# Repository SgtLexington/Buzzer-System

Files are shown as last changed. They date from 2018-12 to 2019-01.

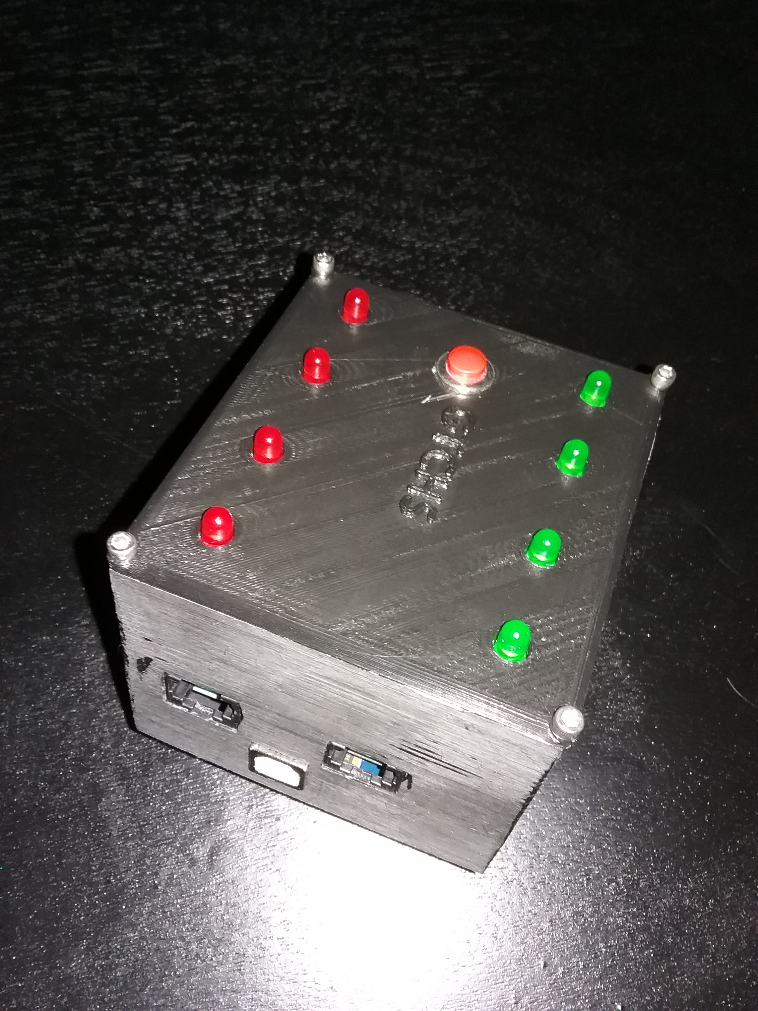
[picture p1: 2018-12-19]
Pictures/20181203_172621.jpg

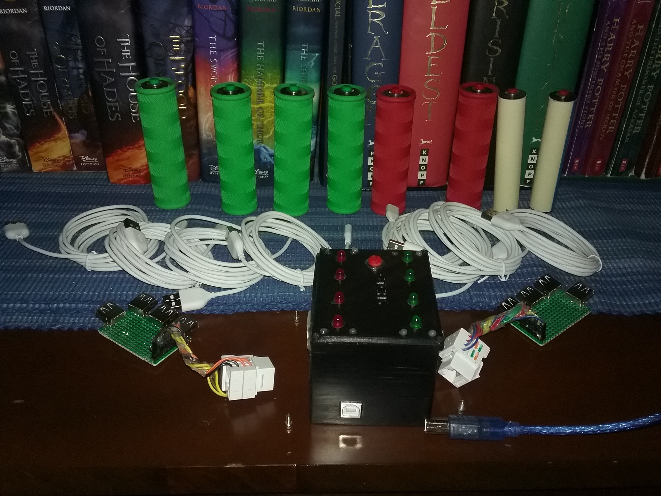
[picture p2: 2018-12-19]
Pictures/20180729_170001.jpg

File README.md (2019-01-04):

# Buzzer-System
The way that academic competitions work is this: to get points, a player must "buzz in" while or after a question has been answered. Then, the player must answer the question correctly. The moderator will take whoever buzzes in first, so it is very important to practice the buzzing motion to do well. My team has lots of talent, but we are always at a disadvantage when we go to competitions becausewe never practice with the equipment that we use at those competions. Usually at practices, to buzz in, we just hit the desk, while at competions there is a handheld buzzer system where the button to buzz in must be activated by a thumb motion. Naturally, we are slightly outperformed in this category by teams that do practice with a real buzzer system. 
The solution is simple: just buy a buzzer system like the ones at the competitions. 
However, decent quality buzzer systems are expensive. Some of the highest quality systems are $200-$300, and my school simply cannot afford something like that. Given that, I decided to make a buzzer system for us.
Not only does having a buzzer system help the team practice better, but if we bring our own buzzer system to a competition, we get a discount on the entry fee.
Here is the finished system:
[insert pic here]
Prototyping
  Protoboards
  Solidworks
The Main Box:
  Arduino Program
  KiCad and PCB
  Solidworks box & lid
The Team Boxes:
  KiCad and PCB
  Solidworks box & lid
The Buzzers:
  Solidworks MicroUSB & button housings

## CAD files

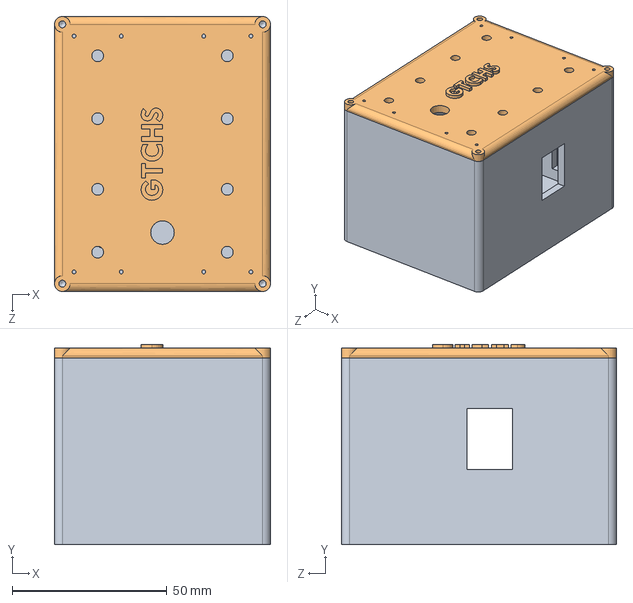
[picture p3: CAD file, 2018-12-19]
SolidWorks/Main box assemb.SLDASM
69.8 x 64.8 x 88.9 mm
Main box
Box lid

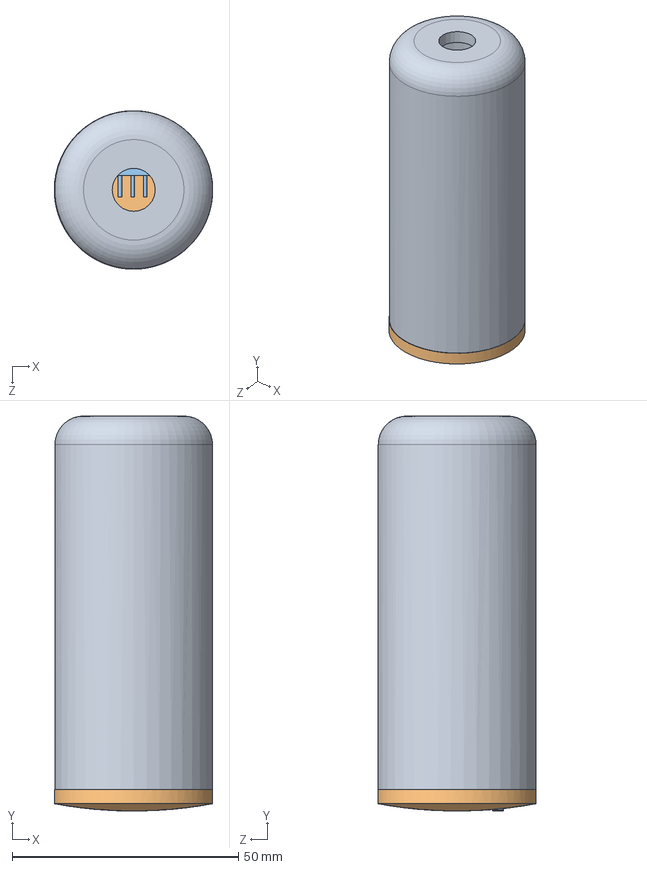
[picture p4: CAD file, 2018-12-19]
SolidWorks/Handheld buzzer housing and breakout board.SLDASM
35.0 x 87.3 x 35.0 mm
Button Housing
Housing bottom
Micro USB Breakout Board

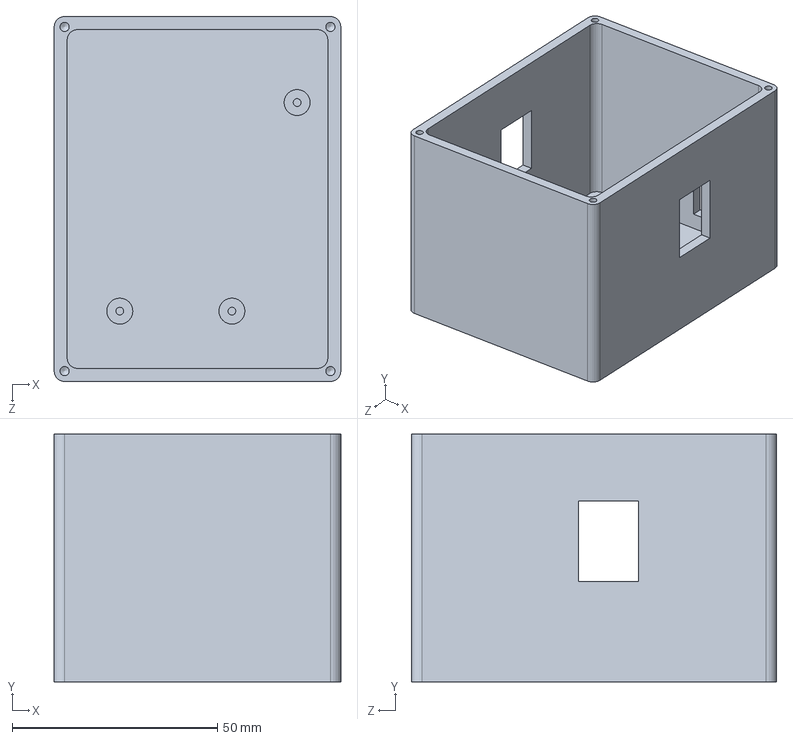
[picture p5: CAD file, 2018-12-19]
SolidWorks/Main box.SLDPRT
69.8 x 60.3 x 88.9 mm

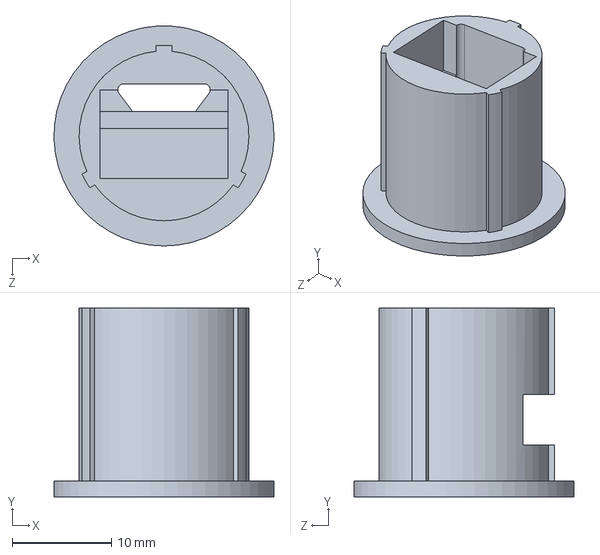
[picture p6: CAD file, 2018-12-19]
SolidWorks/End Cap.SLDPRT
22.2 x 19.1 x 22.2 mm

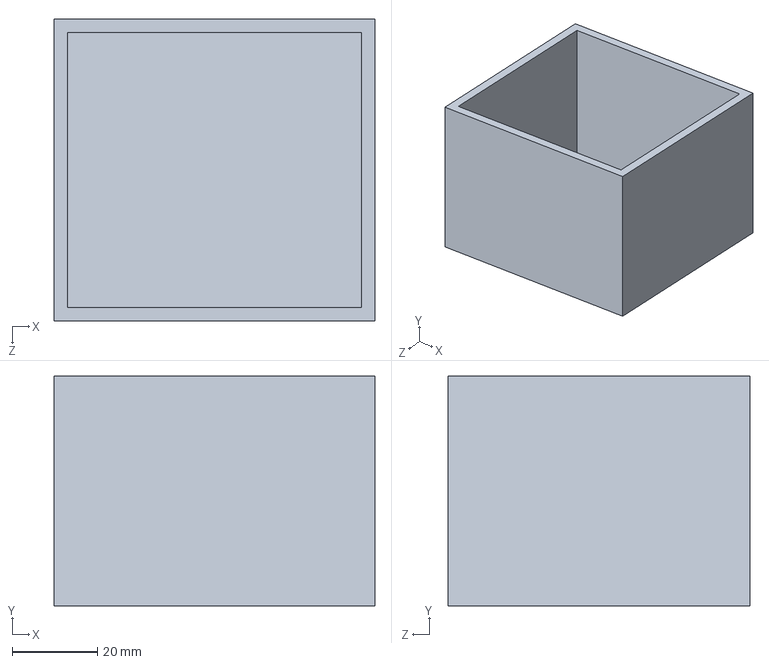
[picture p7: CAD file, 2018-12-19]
SolidWorks/Team box for pcb.SLDPRT
75.4 x 54.0 x 70.9 mm

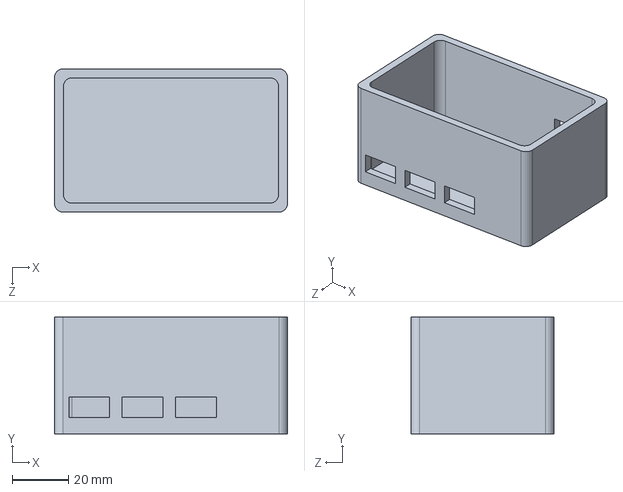
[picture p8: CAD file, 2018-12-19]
SolidWorks/Team box.SLDPRT
82.5 x 41.3 x 50.8 mm

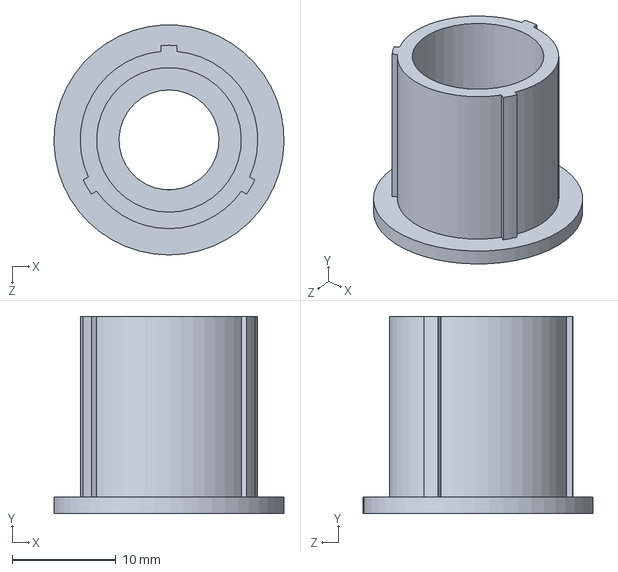
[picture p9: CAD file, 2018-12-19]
SolidWorks/button side end cap.SLDPRT
22.2 x 19.1 x 22.2 mm

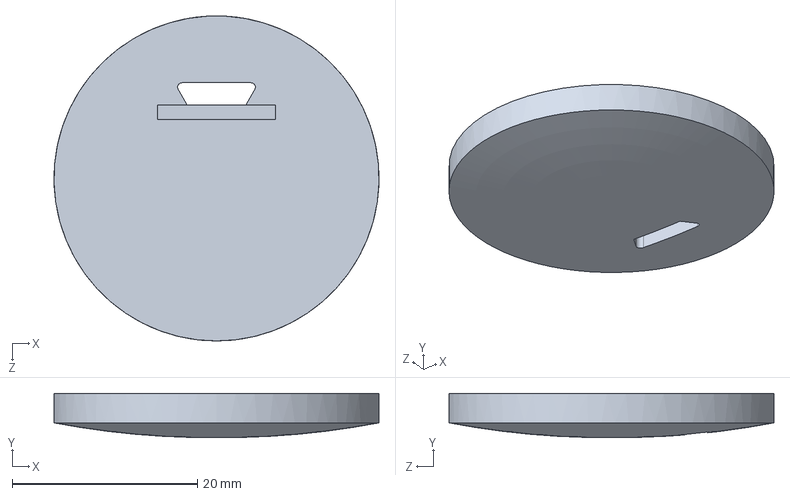
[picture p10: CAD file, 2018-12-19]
SolidWorks/Housing bottom.SLDPRT
35.0 x 4.76 x 35.0 mm

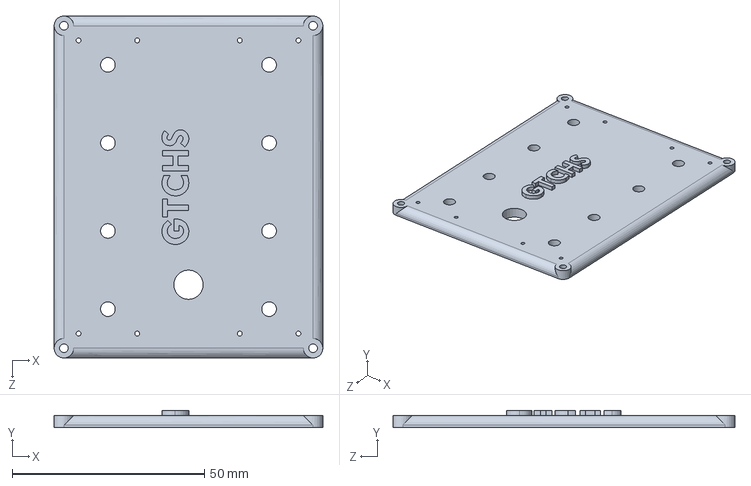
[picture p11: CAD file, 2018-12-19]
SolidWorks/Box lid.SLDPRT
69.8 x 4.45 x 88.9 mm

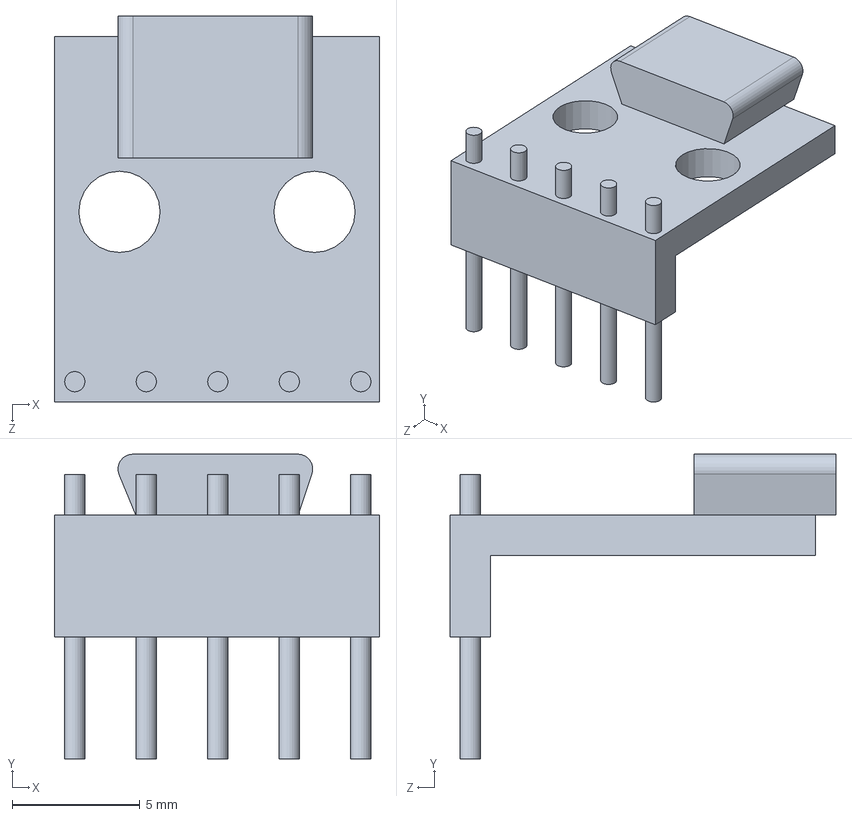
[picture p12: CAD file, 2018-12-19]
SolidWorks/Micro USB Breakout Board.SLDPRT
12.7 x 11.9 x 15.1 mm

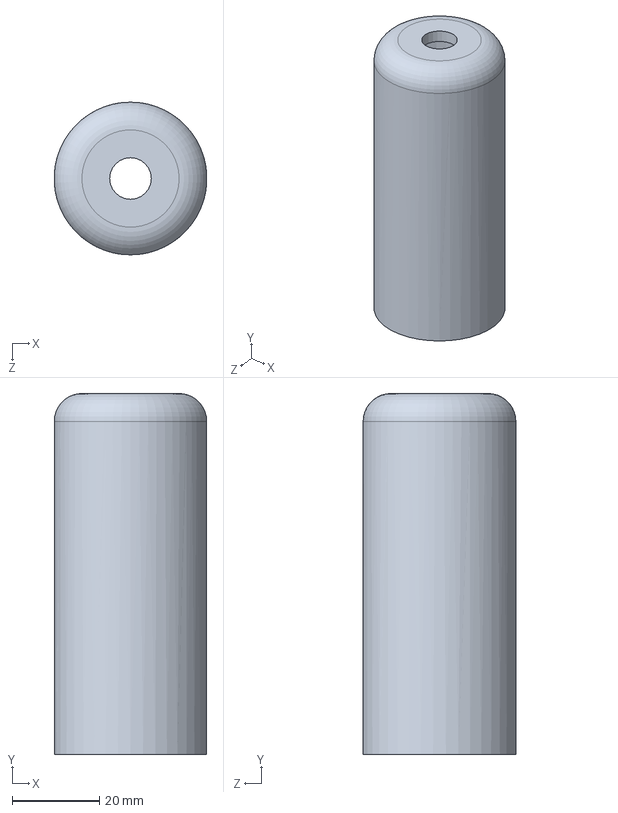
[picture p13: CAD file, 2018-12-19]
SolidWorks/Button Housing.SLDPRT
34.9 x 82.5 x 34.9 mm

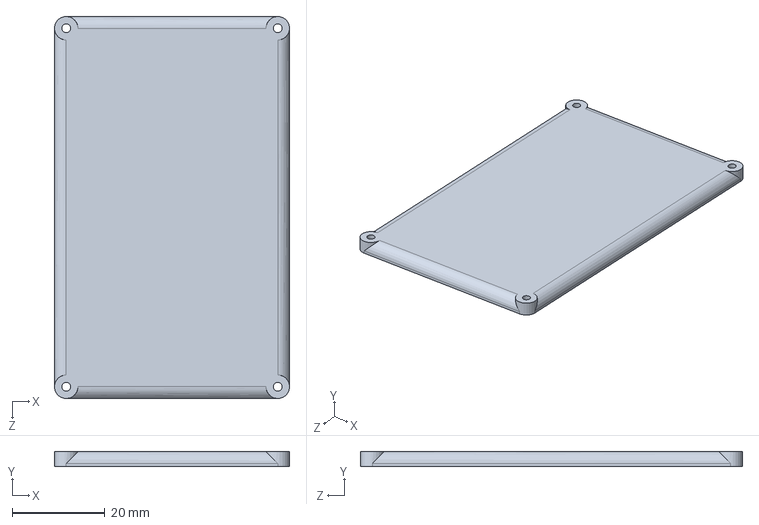
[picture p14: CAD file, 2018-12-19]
SolidWorks/Team box lid.SLDPRT
50.8 x 3.17 x 82.5 mm

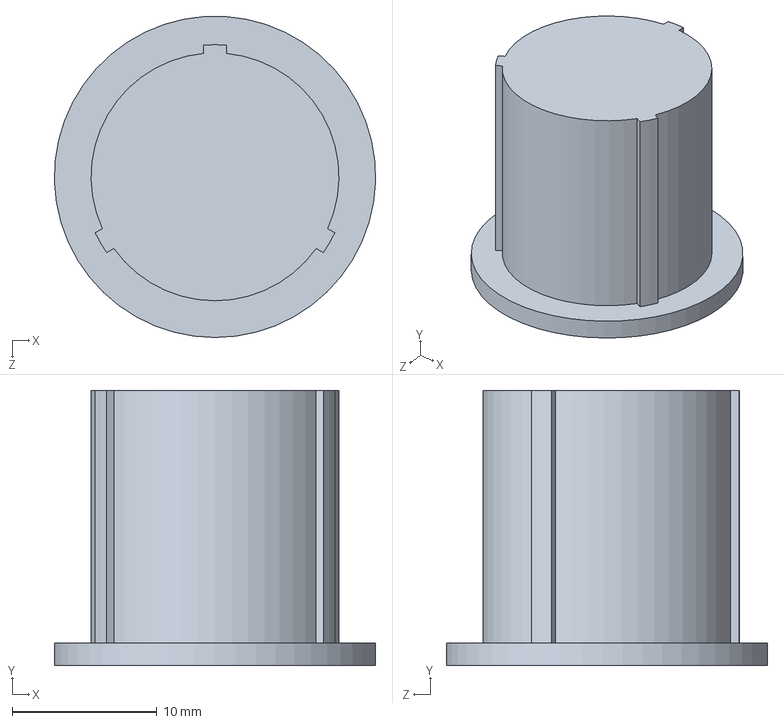
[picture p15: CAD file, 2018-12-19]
SolidWorks/Default end cap.SLDPRT
22.2 x 19.1 x 22.2 mm

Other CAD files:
SolidWorks/Team box opposite.SLDPRT
SolidWorks/End Cap with fingers for breakout holes.SLDPRT
SolidWorks/End Cap no holes for screws.SLDPRT
SolidWorks/Box lid.STL
SolidWorks/End Cap with fingers for breakout holes.STL
SolidWorks/End Cap.STL
SolidWorks/Main box.STL
SolidWorks/Team box lid.STL
SolidWorks/Team box opposite.STL
SolidWorks/Team box.STL
SolidWorks/button side end cap.STL

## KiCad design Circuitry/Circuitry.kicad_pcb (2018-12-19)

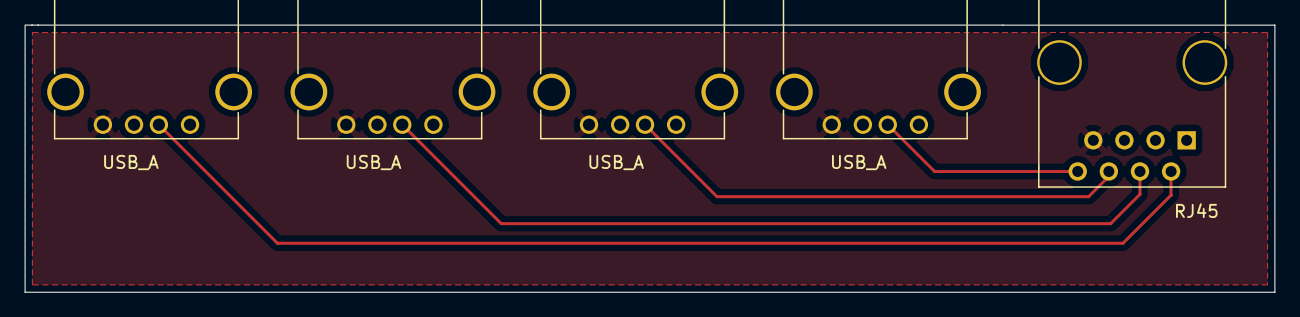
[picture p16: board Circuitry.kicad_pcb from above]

Board: 2 copper layers, 102.0 x 21.8 mm, 5 parts (0 on the bottom side), 5 nets.

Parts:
Green2: RJ45; RJ45_8
Green-1, Green-2, Green-3, Green-4: USB_A

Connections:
unnamed: Green2.2, Green-1.2
unnamed: Green2.7, Green-1.4, Green-2.4, Green-3.4, Green-4.4
unnamed: Green2.4, Green-2.2
unnamed: Green2.6, Green-3.2
unnamed: Green2.8, Green-4.2

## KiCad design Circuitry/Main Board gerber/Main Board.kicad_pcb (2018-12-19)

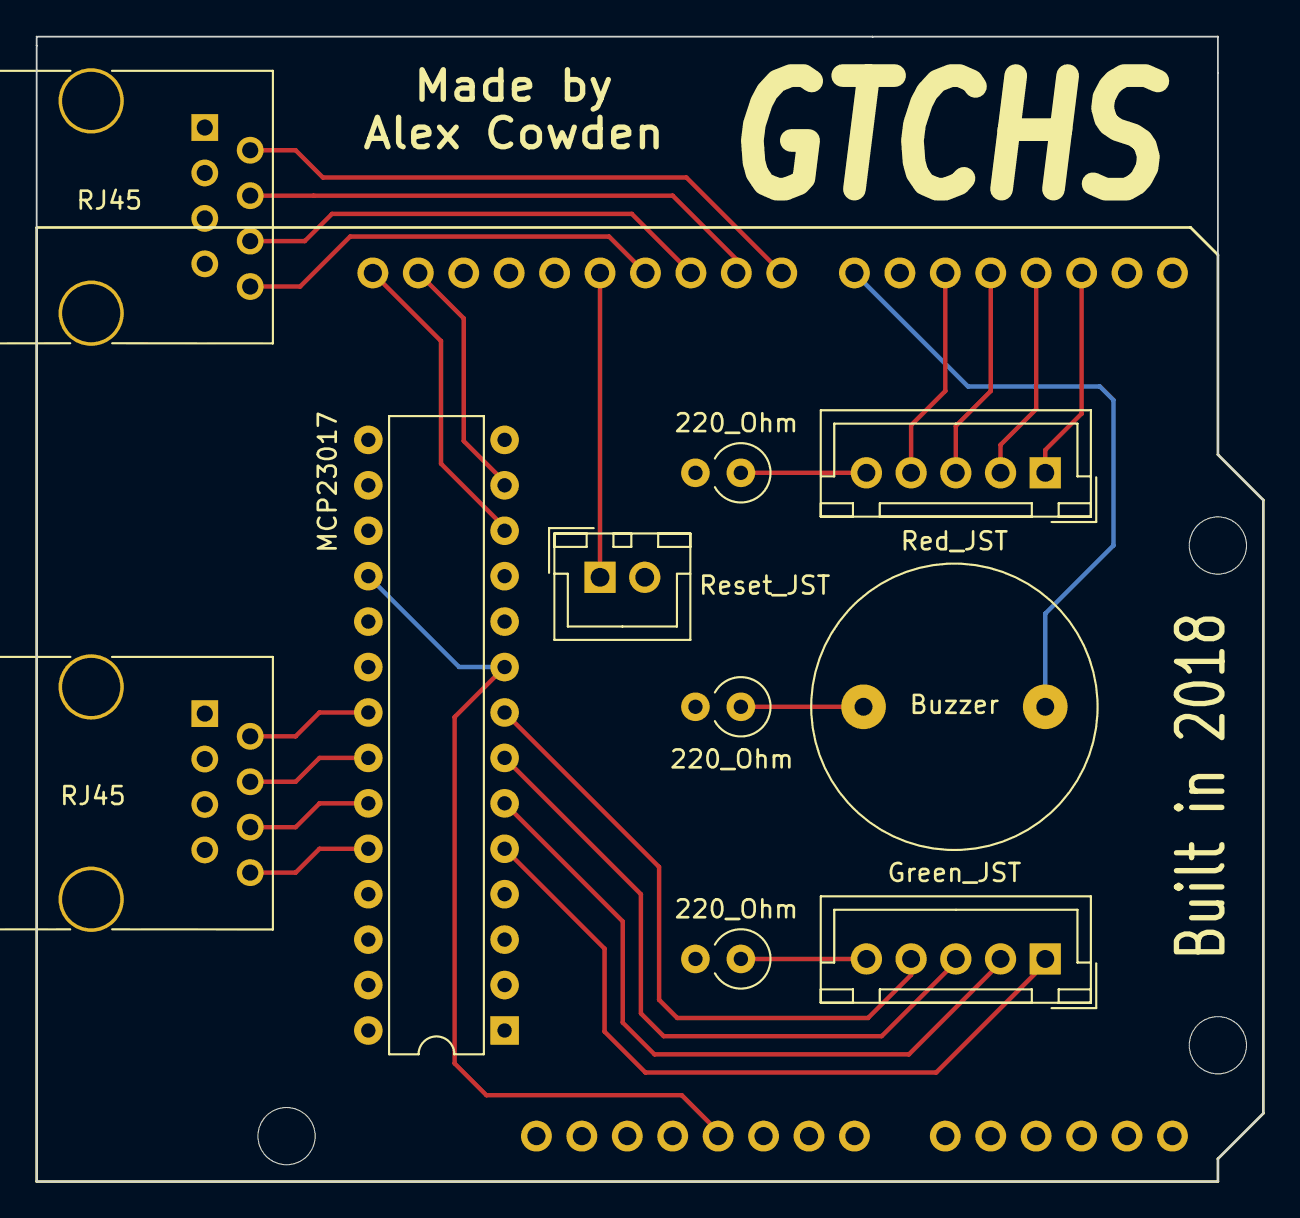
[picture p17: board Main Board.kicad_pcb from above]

Board: 2 copper layers, 68.6 x 64.0 mm, 11 parts (0 on the bottom side), 25 nets.

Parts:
220_Ohm, 220_Ohm#2, 220_Ohm#3: R; R_Axial_DIN0309_L9.0mm_D3.2mm_P2.54mm_Vertical
ARD1: Arduino_Uno_Shield
Green1: RJ45; RJ45_8
Green_JST: Conn_01x05; JST_XH_B05B-XH-A_05x2.50mm_Straight
IOexpander1: MCP23017; DIP-28_W7.62mm
Red1: RJ45; RJ45_8
Red_JST: Conn_01x05; JST_XH_B05B-XH-A_05x2.50mm_Straight
Reset_JST: Conn_01x02; JST_XH_B02B-XH-A_02x2.50mm_Straight
Sound1: Buzzer; BUZZER

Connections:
BTN_RESET: ARD1.D12, Reset_JST.1
BUZZER: ARD1.D7, Sound1.1
CLOCK: ARD1.SCL, IOexpander1.12
DATA: ARD1.SDA, IOexpander1.13
GND: 220_Ohm.2, 220_Ohm#2.2, 220_Ohm#3.2, ARD1.GND1, ARD1.GND2, ARD1.GND3, Green1.7, IOexpander1.10, IOexpander1.15, IOexpander1.16, IOexpander1.17, Red1.7, Reset_JST.2
G_BTN_1: Green1.2, IOexpander1.21
G_BTN_2: Green1.4, IOexpander1.22
G_BTN_3: Green1.6, IOexpander1.23
G_BTN_4: Green1.8, IOexpander1.24
G_LED_1: Green_JST.1, IOexpander1.5
G_LED_2: Green_JST.2, IOexpander1.6
G_LED_3: Green_JST.3, IOexpander1.7
G_LED_4: Green_JST.4, IOexpander1.8
unnamed: 220_Ohm.1, Red_JST.5
unnamed: 220_Ohm#2.1, Green_JST.5
unnamed: 220_Ohm#3.1, Sound1.2
unnamed: ARD1.5V1, IOexpander1.9, IOexpander1.18
R_BTN_1: ARD1.D8, Red1.2
R_BTN_2: ARD1.D9, Red1.4
R_BTN_3: ARD1.D10, Red1.6
R_BTN_4: ARD1.D11, Red1.8
R_LED_1: ARD1.D2, Red_JST.1
R_LED_2: ARD1.D3, Red_JST.2
R_LED_3: ARD1.D4, Red_JST.3
R_LED_4: ARD1.D5, Red_JST.4

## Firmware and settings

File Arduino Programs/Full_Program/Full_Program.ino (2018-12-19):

#include <Wire.h>
#include "Adafruit_MCP23017.h"
Adafruit_MCP23017 mcp;
const int RED_LED_1 = 2;
const int RED_LED_2 = 3;
const int RED_LED_3 = 4;
const int RED_LED_4 = 5;
const int GREEN_LED_1 = 12;
const int GREEN_LED_2 = 13;
const int GREEN_LED_3 = 14;
const int GREEN_LED_4 = 15;
const int RED_BUTTON_1 = 8;
const int RED_BUTTON_2 = 9;
const int RED_BUTTON_3 = 10;
const int RED_BUTTON_4 = 11;
const int GREEN_BUTTON_1 = 0;
const int GREEN_BUTTON_2 = 1;
const int GREEN_BUTTON_3 = 2;
const int GREEN_BUTTON_4 = 3;
const int RESET_BUTTON = 12;
const int BUZZER = 7;
int red1On = 0;
int red2On = 0;
int red3On = 0;
int red4On = 0;
int green1On = 0;
int green2On = 0;
int green3On = 0;
int green4On = 0;
void setup() {
  pinMode(RED_LED_1, OUTPUT);
  pinMode(RED_LED_2, OUTPUT);
  pinMode(RED_LED_3, OUTPUT);
  pinMode(RED_LED_4, OUTPUT);
  pinMode(RED_BUTTON_1, INPUT_PULLUP);
  pinMode(RED_BUTTON_2, INPUT_PULLUP);
  pinMode(RED_BUTTON_3, INPUT_PULLUP);
  pinMode(RED_BUTTON_4, INPUT_PULLUP); 
  pinMode(RESET_BUTTON, INPUT_PULLUP);
  pinMode(BUZZER, OUTPUT);
  mcp.begin();
  mcp.pinMode(GREEN_BUTTON_1, INPUT);
  mcp.pinMode(GREEN_BUTTON_2, INPUT);
  mcp.pinMode(GREEN_BUTTON_3, INPUT);
  mcp.pinMode(GREEN_BUTTON_4, INPUT);
  mcp.pullUp(GREEN_BUTTON_1, HIGH);
  mcp.pullUp(GREEN_BUTTON_2, HIGH);
  mcp.pullUp(GREEN_BUTTON_3, HIGH);
  mcp.pullUp(GREEN_BUTTON_4, HIGH);
  mcp.pinMode(GREEN_LED_1, OUTPUT);
  mcp.pinMode(GREEN_LED_2, OUTPUT);
  mcp.pinMode(GREEN_LED_3, OUTPUT);
  mcp.pinMode(GREEN_LED_4, OUTPUT);
  //mcp.begin();      // use default address 0
 // mcp.pinMode(0, INPUT);
 // mcp.pullUp(0, HIGH);  // turn on a 100K pullup internally
  //pinMode(13, OUTPUT);  // use the p13 LED as debugging
}

void loop() {
  if (digitalRead(RED_BUTTON_1) == LOW && red1On == 0 && red2On == 0 && red3On == 0 && red4On == 0 && green1On == 0 && green2On == 0 && green3On == 0 && green4On == 0) {      //This code runs the lockout circuit.
      digitalWrite(RED_LED_1, HIGH);
      red1On = 1;
      red2On = 1;
      red3On = 1;
      red4On = 1;
      green1On = 1;
      green2On = 1;
      green3On = 1;
      green4On = 1;
      tone(BUZZER, 750, 700);
  } else {}
 
  if (digitalRead(RED_BUTTON_2) == LOW && red1On == 0 && red2On == 0 && red3On == 0 && red4On == 0 && green1On == 0 && green2On == 0 && green3On == 0 && green4On == 0) {           
      digitalWrite(RED_LED_2, HIGH);
      red1On = 1;
      red2On = 1;
      red3On = 1;
      red4On = 1;
      green1On = 1;
      green2On = 1;
      green3On = 1;
      green4On = 1;
      tone(BUZZER, 750, 700);            
  } else {}
  
  if (digitalRead(RED_BUTTON_3) == LOW && red1On == 0 && red2On == 0 && red3On == 0 && red4On == 0 && green1On == 0 && green2On == 0 && green3On == 0 && green4On == 0) {           
      digitalWrite(RED_LED_3, HIGH);
      red1On = 1;
      red2On = 1;
      red3On = 1;
      red4On = 1;
      green1On = 1;
      green2On = 1;
      green3On = 1;
      green4On = 1;
      tone(BUZZER, 750, 700);                
  } else {}
  
  if (digitalRead(RED_BUTTON_4) == LOW && red1On == 0 && red2On == 0 && red3On == 0 && red4On == 0 && green1On == 0 && green2On == 0 && green3On == 0 && green4On == 0) {           
      digitalWrite(RED_LED_4, HIGH);
      red1On = 1;
      red2On = 1;
      red3On = 1;
      red4On = 1;
      green1On = 1;
      green2On = 1;
      green3On = 1;
      green4On = 1;
      tone(BUZZER, 750, 700);                
  } else {}

  if (mcp.digitalRead(GREEN_BUTTON_1) == LOW && red1On == 0 && red2On == 0 && red3On == 0 && red4On == 0 && green1On == 0 && green2On == 0 && green3On == 0 && green4On == 0) {
      mcp.digitalWrite(GREEN_LED_1, HIGH);
      red1On = 1;
      red2On = 1;
      red3On = 1;
      red4On = 1;
      green1On = 1;
      green2On = 1;
      green3On = 1;
      green4On = 1;
      tone(BUZZER, 500, 700);
  } else {}
  
  if (mcp.digitalRead(GREEN_BUTTON_2) == LOW && red1On == 0 && red2On == 0 && red3On == 0 && red4On == 0 && green1On == 0 && green2On == 0 && green3On == 0 && green4On == 0) {
      mcp.digitalWrite(GREEN_LED_2, HIGH);
      red1On = 1;
      red2On = 1;
      red3On = 1;
      red4On = 1;
      green1On = 1;
      green2On = 1;
      green3On = 1;
      green4On = 1;
      tone(BUZZER, 500, 700);
  } else {}

  if (mcp.digitalRead(GREEN_BUTTON_3) == LOW && red1On == 0 && red2On == 0 && red3On == 0 && red4On == 0 && green1On == 0 && green2On == 0 && green3On == 0 && green4On == 0) {
      mcp.digitalWrite(GREEN_LED_3, HIGH);
      red1On = 1;
      red2On = 1;
      red3On = 1;
      red4On = 1;
      green1On = 1;
      green2On = 1;
      green3On = 1;
      green4On = 1;
      tone(BUZZER, 500, 700);
  } else {}

    if (mcp.digitalRead(GREEN_BUTTON_4) == LOW && red1On == 0 && red2On == 0 && red3On == 0 && red4On == 0 && green1On == 0 && green2On == 0 && green3On == 0 && green4On == 0) {
      mcp.digitalWrite(GREEN_LED_4, HIGH);
      red1On = 1;
      red2On = 1;
      red3On = 1;
      red4On = 1;
      green1On = 1;
      green2On = 1;
      green3On = 1;
      green4On = 1;
      tone(BUZZER, 500, 700);
  } else {}
  
  if (digitalRead(RESET_BUTTON) == LOW) {                    //This code resets the circuit
     red1On = 0;
     red2On = 0;
     red3On = 0;
     red4On = 0;
     green1On = 0;
     green2On = 0;
     green3On = 0;
     green4On = 0;
     digitalWrite(RED_LED_1, LOW);
     digitalWrite(RED_LED_2, LOW);
     digitalWrite(RED_LED_3, LOW);
     digitalWrite(RED_LED_4, LOW);
     mcp.digitalWrite(GREEN_LED_1, LOW);
     mcp.digitalWrite(GREEN_LED_2, LOW);
     mcp.digitalWrite(GREEN_LED_3, LOW);
     mcp.digitalWrite(GREEN_LED_4, LOW);
  }  else {}                               
}
